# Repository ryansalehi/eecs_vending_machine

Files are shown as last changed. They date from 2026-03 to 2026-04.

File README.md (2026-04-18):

# EECS Sticker Vending Machine
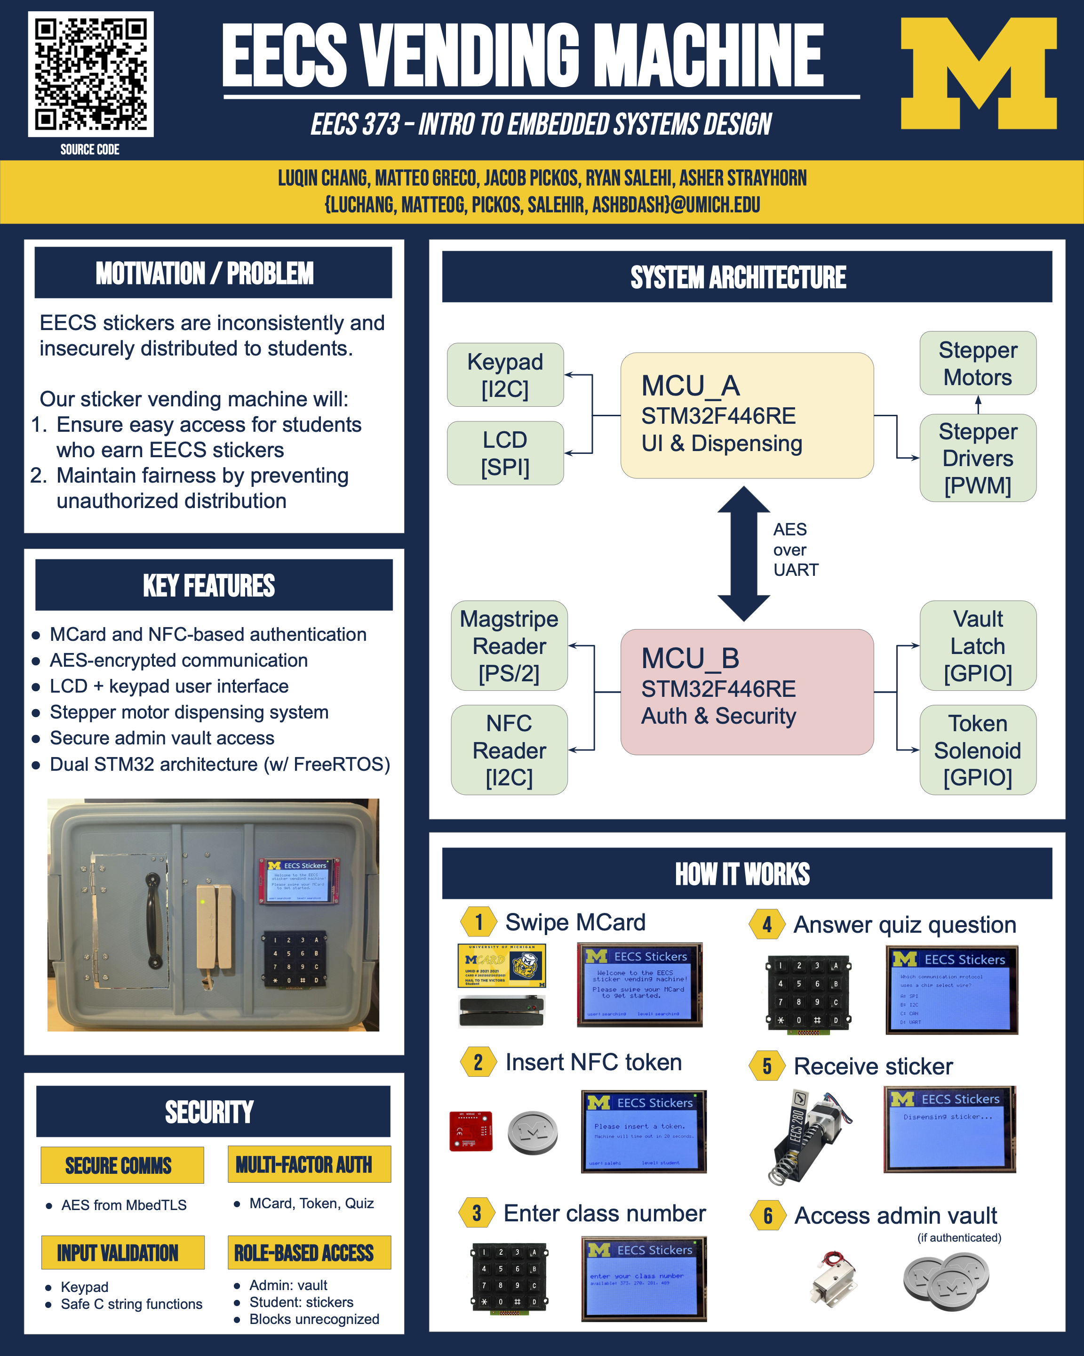
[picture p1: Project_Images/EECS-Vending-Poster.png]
Poster for Project Expo


# MCU_A Pinout
LCD:
- PA4 CS
- PB0 RESET
- PB1 DC
- PA7 MOSI
- PA6 MISO
- PB3 SCK
- 3.3V LED

Keypad:
- PB6 SCL
- PB9 SDA
- PA9 INT

UART:
- PC10 UART_TX
- PC11 UART_RX

Motors:
- PC8 Step
- PC9 Dir
- PB4 EN1
- PB5 EN2
- PB13 EN3
- PB14 EN4

# MCU_B Pinout
Token NFC:
- PB8 SCL
- PB9 SDA
- PC13 IRQ
- PA8 RESET

PS/2 Magstripe Reader:
- PC0 CLOCK
- PC1 DATA

UART:
- PC10 UART_TX
- PC11 UART_RX

DOOR LATCHES:
- PC2 ADMIN DOOR
- PC3 TOKEN DROP

# Keypad Pinout

With pin 0 as the pin closest to the * button:
- Pin 0: Row 1
- Pin 1: Row 2
- Pin 2: Col 0
- Pin 3: Row 3
- Pin 4: Col 1
- Pin 5: Col 2
- Pin 6: Col 3
- Pin 7: Row 0

When read, column value is 1-based and row value is 0-based

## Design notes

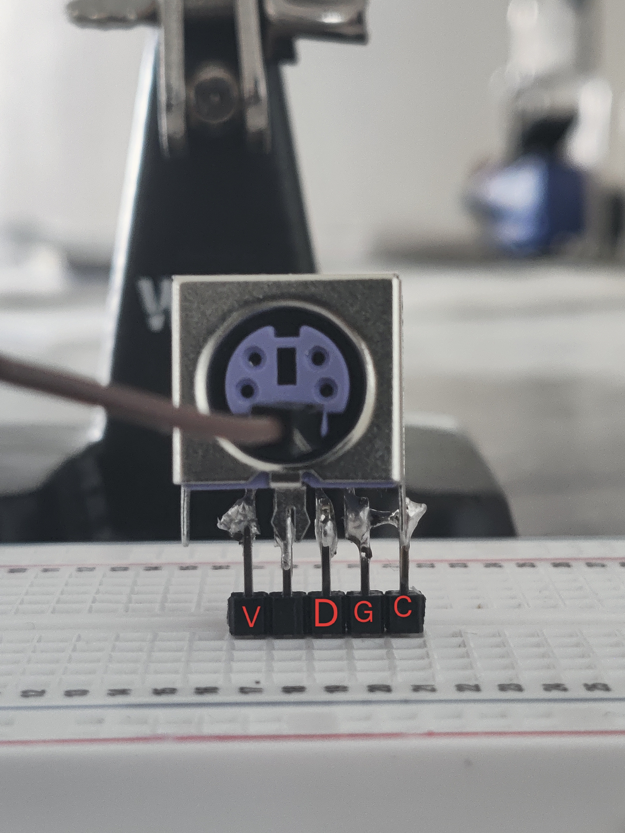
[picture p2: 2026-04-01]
Datasheets/ps2-connector-pinout.jpg

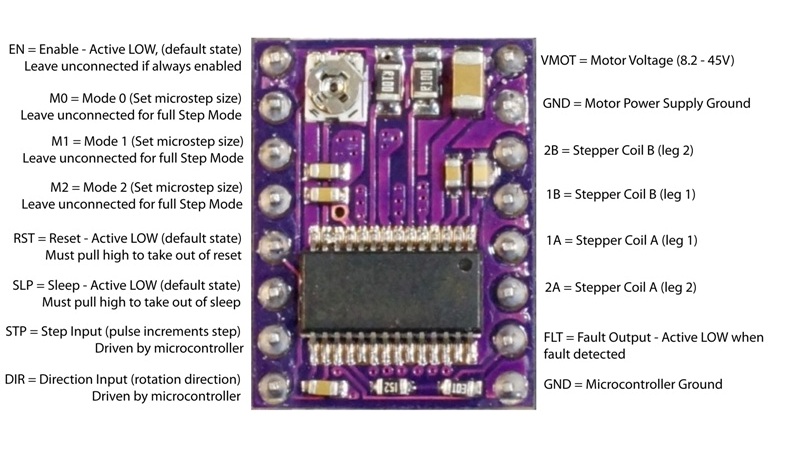
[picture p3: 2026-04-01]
Datasheets/DRV8825-Pinout-2.jpg

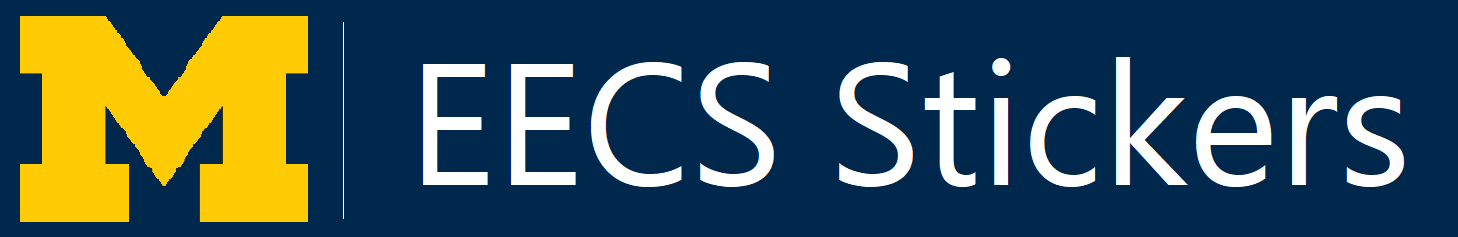
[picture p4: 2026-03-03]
Project_Images/header.png

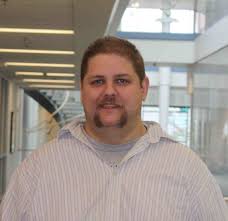
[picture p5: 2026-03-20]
Datasheets/ronald.jpg

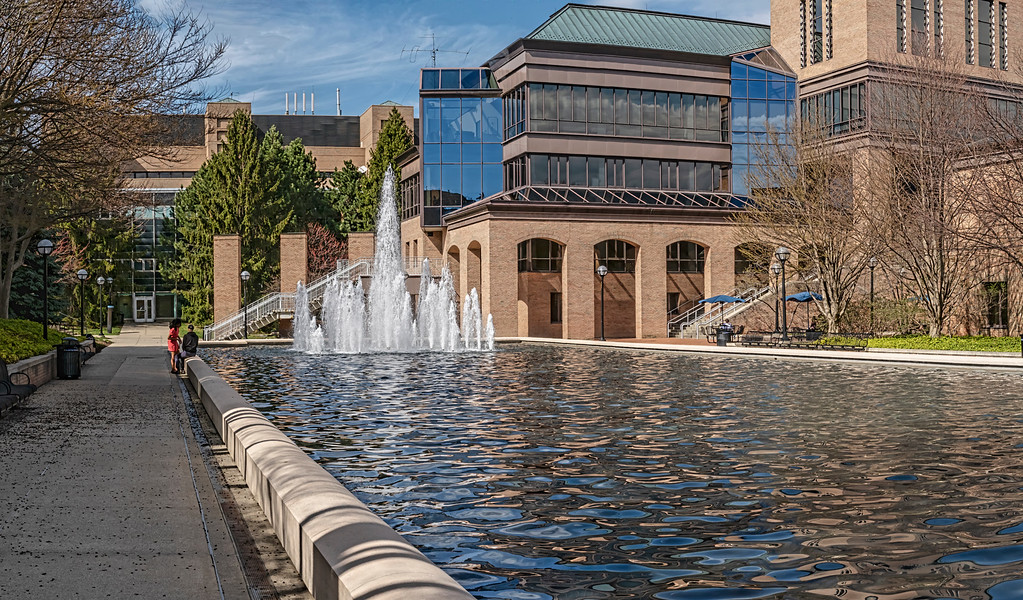
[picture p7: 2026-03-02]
Project_Images/north.png

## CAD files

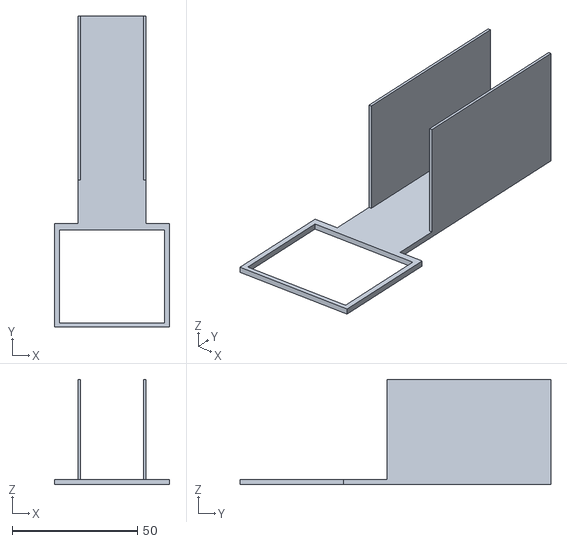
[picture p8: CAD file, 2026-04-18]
CAD/Incredible Stantia-Jofo.stl
46.0 x 124.3 x 42.0

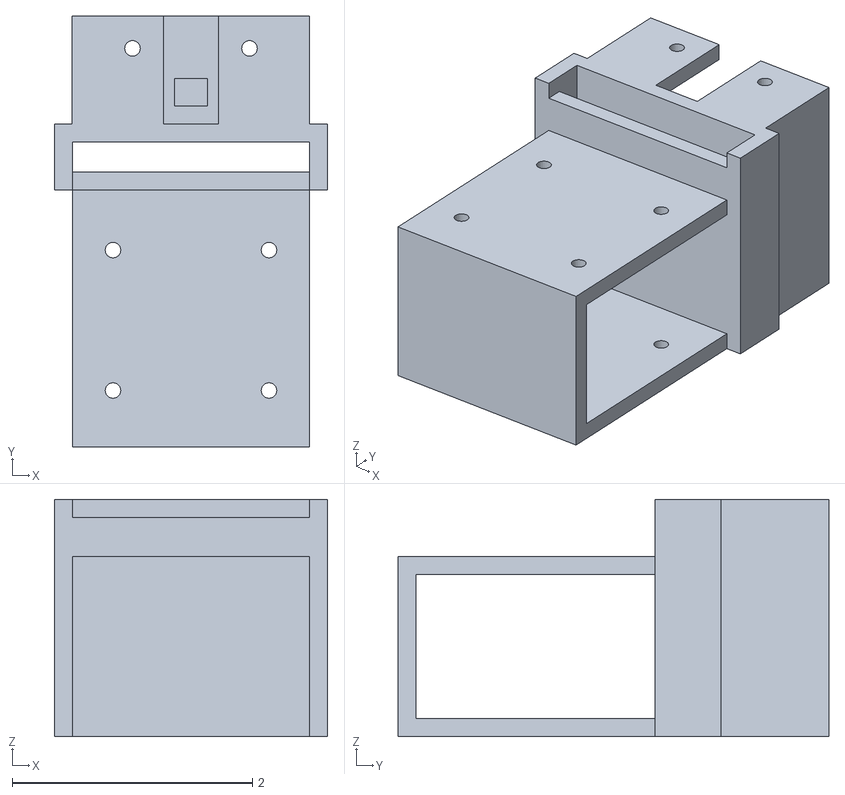
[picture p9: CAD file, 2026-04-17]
CAD/NFCHolderWithLatch.stl
2.28 x 3.59 x 1.97

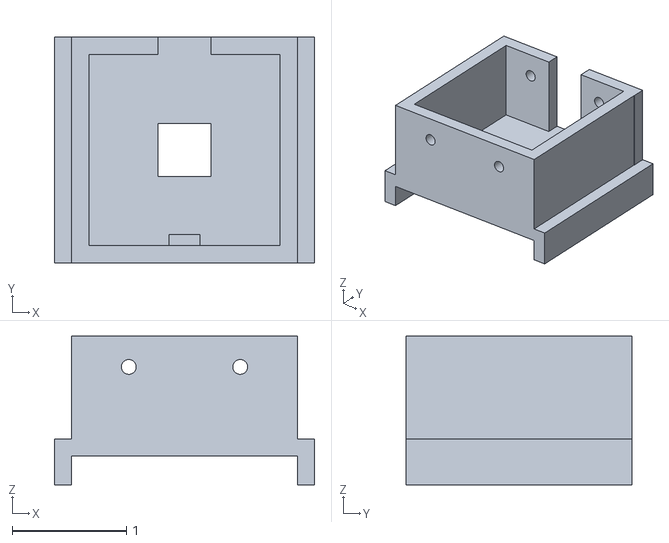
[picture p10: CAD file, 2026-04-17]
CAD/NFCHolder.stl
2.28 x 1.97 x 1.30

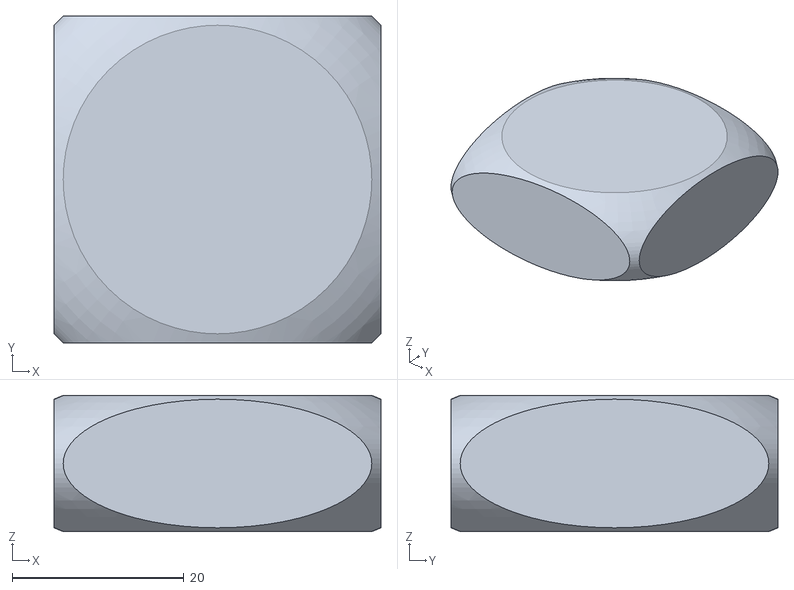
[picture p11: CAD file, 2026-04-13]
CAD/Stunning Albar-Crift.stl
38.1 x 38.1 x 15.9

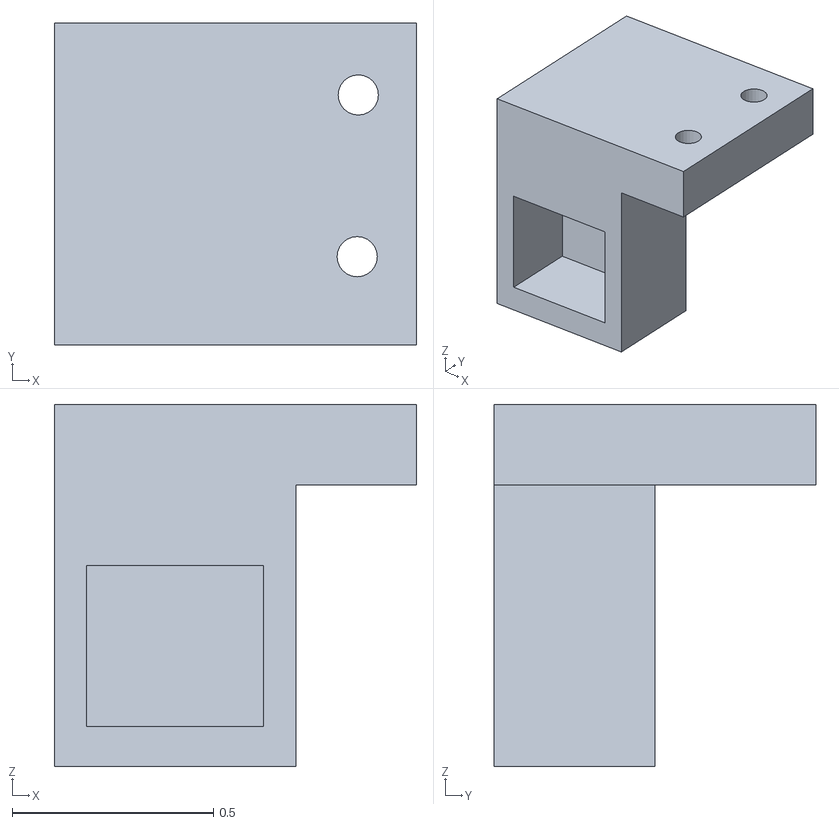
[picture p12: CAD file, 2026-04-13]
CAD/latch.stl
0.9 x 0.8 x 0.9

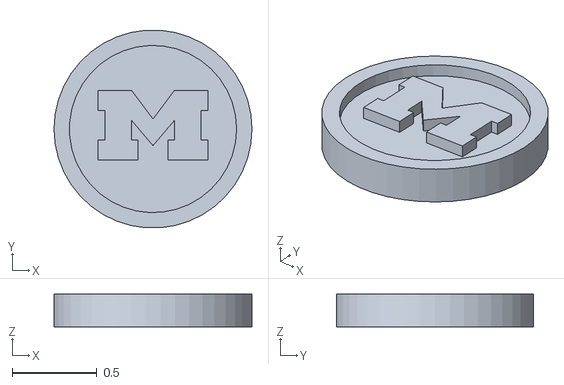
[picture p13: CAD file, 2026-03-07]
CAD/Token_v1_2.stl
1.17 x 1.17 x 0.195

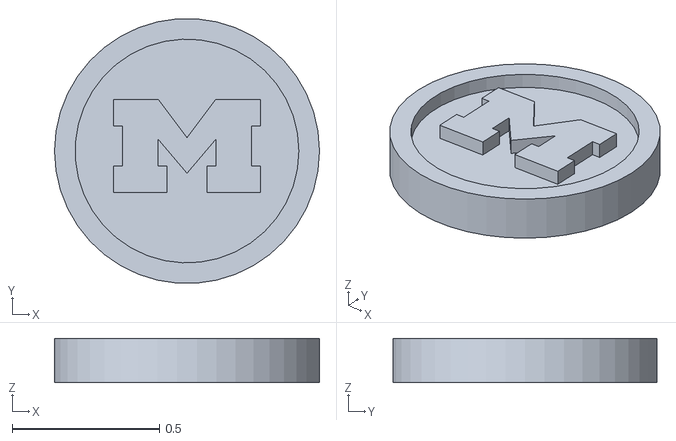
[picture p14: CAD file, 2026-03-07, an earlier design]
CAD/Token_v1_1.stl
0.9 x 0.897 x 0.15

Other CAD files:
CAD/Token.dwg
CAD/NFCHolder.dwg
CAD/NFCHolderWithLatch.dwg
CAD/latch.dwg

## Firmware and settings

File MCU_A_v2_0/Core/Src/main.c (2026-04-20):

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
/* Includes ------------------------------------------------------------------*/
#include "main.h"
#include "cmsis_os.h"
#include "mbedtls.h"

/* USER CODE BEGIN Includes */
#include "lcd.h"
#include "keypad.h"
#include "motors.h"
#include "sender.h"
#include "receiver.h"
#include "statemachine.h"

/* USER CODE END Includes */

I2C_HandleTypeDef hi2c1;

SPI_HandleTypeDef hspi1;

TIM_HandleTypeDef htim3;

UART_HandleTypeDef huart3;

/* Definitions for LCDTask */
osThreadId_t LCDTaskHandle;
const osThreadAttr_t LCDTask_attributes = {
  .name = "LCDTask",
  .stack_size = 128 * 4,
  .priority = (osPriority_t) osPriorityNormal,
};
/* Definitions for KEYPADTask */
osThreadId_t KEYPADTaskHandle;
const osThreadAttr_t KEYPADTask_attributes = {
  .name = "KEYPADTask",
  .stack_size = 128 * 4,
  .priority = (osPriority_t) osPriorityLow,
};
/* Definitions for UARTTask */
osThreadId_t UARTTaskHandle;
const osThreadAttr_t UARTTask_attributes = {
  .name = "UARTTask",
  .stack_size = 128 * 4,
  .priority = (osPriority_t) osPriorityLow,
};
/* Definitions for HEARTBEATTask */
osThreadId_t HEARTBEATTaskHandle;
const osThreadAttr_t HEARTBEATTask_attributes = {
  .name = "HEARTBEATTask",
  .stack_size = 128 * 4,
  .priority = (osPriority_t) osPriorityLow,
};
/* Definitions for SMTask */
osThreadId_t SMTaskHandle;
const osThreadAttr_t SMTask_attributes = {
  .name = "SMTask",
  .stack_size = 256 * 4,
  .priority = (osPriority_t) osPriorityLow,
};
void SystemClock_Config(void);
static void MX_GPIO_Init(void);
static void MX_I2C1_Init(void);
static void MX_SPI1_Init(void);
static void MX_USART3_UART_Init(void);
static void MX_TIM3_Init(void);
void StartLCDTask(void *argument);
void StartKEYPADTask(void *argument);
void StartUARTTask(void *argument);
void StartHEARTBEATTask(void *argument);
void StartSMTask(void *argument);

/**
  * @brief  The application entry point.
  * @retval int
  */
int main(void)
{

  /* MCU Configuration--------------------------------------------------------*/

  /* Reset of all peripherals, Initializes the Flash interface and the Systick. */
  HAL_Init();

  /* Configure the system clock */
  SystemClock_Config();

  /* Initialize all configured peripherals */
  MX_GPIO_Init();
  MX_I2C1_Init();
  MX_SPI1_Init();
  MX_USART3_UART_Init();
  MX_TIM3_Init();
  /* Call PreOsInit function */
  MX_MBEDTLS_Init();
  /* USER CODE BEGIN 2 */
  Receiver_StartHardwareListening();

  /* USER CODE END 2 */

  /* Init scheduler */
  osKernelInitialize();

  /* USER CODE BEGIN RTOS_MUTEX */
  LCD_Init();
  KEYPAD_Init();
  UART_Init();
  /* USER CODE END RTOS_MUTEX */

  /* USER CODE BEGIN RTOS_SEMAPHORES */
  /* add semaphores, ... */
  /* USER CODE END RTOS_SEMAPHORES */

  /* USER CODE BEGIN RTOS_TIMERS */
  /* start timers, add new ones, ... */
  /* USER CODE END RTOS_TIMERS */

  /* USER CODE BEGIN RTOS_QUEUES */
  /* add queues, ... */
  /* USER CODE END RTOS_QUEUES */

  /* Create the thread(s) */
  /* creation of LCDTask */
  LCDTaskHandle = osThreadNew(StartLCDTask, NULL, &LCDTask_attributes);

  /* creation of KEYPADTask */
  KEYPADTaskHandle = osThreadNew(StartKEYPADTask, NULL, &KEYPADTask_attributes);

  /* creation of UARTTask */
  UARTTaskHandle = osThreadNew(StartUARTTask, NULL, &UARTTask_attributes);

  /* creation of HEARTBEATTask */
  HEARTBEATTaskHandle = osThreadNew(StartHEARTBEATTask, NULL, &HEARTBEATTask_attributes);

  /* creation of SMTask */
  SMTaskHandle = osThreadNew(StartSMTask, NULL, &SMTask_attributes);

  /* USER CODE BEGIN RTOS_THREADS */
  /* add threads, ... */
  /* USER CODE END RTOS_THREADS */

  /* USER CODE BEGIN RTOS_EVENTS */
  /* add events, ... */
  /* USER CODE END RTOS_EVENTS */

  /* Start scheduler */
  osKernelStart();

  /* We should never get here as control is now taken by the scheduler */

  /* Infinite loop */
  /* USER CODE BEGIN WHILE */
  while (1)
  {
    /* USER CODE END WHILE */
    /* USER CODE BEGIN 3 */
    osDelay(5000);

  }
  /* USER CODE END 3 */
}

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
/* USER CODE BEGIN 4 */
void HAL_GPIO_EXTI_Callback(uint16_t GPIO_Pin)
{
  KEYPAD_IrqFromIsr();
}
/* USER CODE END 4 */

/* USER CODE BEGIN Header_StartLCDTask */
/**
  * @brief  Function implementing the LCDTask thread.
  * @param  argument: Not used
  * @retval None
  */
/* USER CODE END Header_StartLCDTask */
void StartLCDTask(void *argument)
{
  /* USER CODE BEGIN 5 */
  /* Infinite loop */
  for(;;)
  {
    LCD_Render();
    osDelay(1);
  }
  /* USER CODE END 5 */
}

/* USER CODE BEGIN Header_StartKEYPADTask */
/**
* @brief Function implementing the KEYPADTask thread.
* @param argument: Not used
* @retval None
*/
/* USER CODE END Header_StartKEYPADTask */
void StartKEYPADTask(void *argument)
{
  /* USER CODE BEGIN StartKEYPADTask */
  /* Infinite loop */
  for(;;)
  {
    KEYPAD_ReadAnyPresses();
    osDelay(1);
  }
  /* USER CODE END StartKEYPADTask */
}

/* USER CODE BEGIN Header_StartUARTTask */
/**
* @brief Function implementing the UARTTask thread.
* @param argument: Not used
* @retval None
*/
/* USER CODE END Header_StartUARTTask */
void StartUARTTask(void *argument)
{
  /* USER CODE BEGIN StartUARTTask */
  for(;;)
  {
    Receiver_Process();
  }
  /* USER CODE END StartUARTTask */
}

/* USER CODE BEGIN Header_StartHEARTBEATTask */
/**
* @brief Function implementing the HEARTBEATTask thread.
* @param argument: Not used
* @retval None
*/
/* USER CODE END Header_StartHEARTBEATTask */
void StartHEARTBEATTask(void *argument)
{
  /* USER CODE BEGIN StartHEARTBEATTask */
  uint8_t val = 0;
  
  for(;;)
  {
    val++;
	  HAL_GPIO_TogglePin(GPIOA, GPIO_PIN_5); // Toggle Blue LED
    LCD_BeginFrame();
    if(val % 2 == 0)
    {
      LCD_FillRect(470, 0, 10, 10, 0, 39, 76);
    }
    else
    {
      LCD_FillRect(470, 0, 10, 10, 0, 255, 0);
    }
    LCD_EndFrame();
	  osDelay(1000);                          // DO NOT use HAL_Delay() here
  }
  /* USER CODE END StartHEARTBEATTask */
}

/* USER CODE BEGIN Header_StartSMTask */
/**
* @brief Function implementing the SMTask thread.
* @param argument: Not used
* @retval None
*/
/* USER CODE END Header_StartSMTask */
void StartSMTask(void *argument)
{
  /* USER CODE BEGIN StartSMTask */
  /* Infinite loop */
  for(;;)
  {
    SM_Run();
  }
  /* USER CODE END StartSMTask */
}

/**
  * @brief  Period elapsed callback in non blocking mode
  * @note   This function is called  when TIM6 interrupt took place, inside
  * HAL_TIM_IRQHandler(). It makes a direct call to HAL_IncTick() to increment
  * a global variable "uwTick" used as application time base.
  * @param  htim : TIM handle
  * @retval None
  */
void HAL_TIM_PeriodElapsedCallback(TIM_HandleTypeDef *htim)
{
  if (htim->Instance == TIM6)
  {
    HAL_IncTick();
  }
}

/**
  * @brief  This function is executed in case of error occurrence.
  * @retval None
  */
void Error_Handler(void)
{
  /* USER CODE BEGIN Error_Handler_Debug */
  /* User can add his own implementation to report the HAL error return state */
  __disable_irq();
  while (1)
  {
  }
  /* USER CODE END Error_Handler_Debug */
}
#ifdef USE_FULL_ASSERT
/**
  * @brief  Reports the name of the source file and the source line number
  *         where the assert_param error has occurred.
  * @param  file: pointer to the source file name
  * @param  line: assert_param error line source number
  * @retval None
  */
void assert_failed(uint8_t *file, uint32_t line)
{
  /* USER CODE BEGIN 6 */
  /* User can add his own implementation to report the file name and line number,
     ex: printf("Wrong parameters value: file %s on line %d\r\n", file, line) */
  /* USER CODE END 6 */
}
#endif /* USE_FULL_ASSERT */

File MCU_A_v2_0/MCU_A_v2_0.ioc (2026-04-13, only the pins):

Mcu.UserName=STM32F446RETx
PA13.GPIO_Label=TMS
PA13.Signal=SYS_JTMS-SWDIO
PA14.GPIO_Label=TCK
PA14.Signal=SYS_JTCK-SWCLK
PA2.GPIO_Label=USART_TX
PA2.Signal=USART2_TX
PA3.GPIO_Label=USART_RX
PA3.Signal=USART2_RX
PA4.Signal=GPIO_Output
PA5.GPIO_Label=LD2 [Green Led]
PA5.Signal=GPIO_Output
PA6.Signal=SPI1_MISO
PA7.Signal=SPI1_MOSI
PA9.Signal=GPXTI9
PB0.Signal=GPIO_Output
PB1.Signal=GPIO_Output
PB13.GPIO_Label=enable_motor3
PB13.Signal=GPIO_Output
PB14.GPIO_Label=enable_motor4
PB14.Signal=GPIO_Output
PB3.Signal=SPI1_SCK
PB4.GPIO_Label=enable_motor1
PB4.Signal=GPIO_Output
PB5.GPIO_Label=enable_motor2
PB5.Signal=GPIO_Output
PB6.Signal=I2C1_SCL
PB9.Signal=I2C1_SDA
PC10.Signal=USART3_TX
PC11.Signal=USART3_RX
PC13.GPIO_Label=B1 [Blue PushButton]
PC13.Signal=GPXTI13
PC14-OSC32_IN.Signal=RCC_OSC32_IN
PC15-OSC32_OUT.Signal=RCC_OSC32_OUT
PC8.GPIO_Label=motor_step
PC8.Signal=S_TIM3_CH3
PC9.GPIO_Label=motor_direction
PC9.Signal=GPIO_Output
PH0-OSC_IN.Signal=RCC_OSC_IN
PH1-OSC_OUT.Signal=RCC_OSC_OUT

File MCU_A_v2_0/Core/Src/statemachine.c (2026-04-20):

/**
 * @date April 10, 2026
 */

#include "statemachine.h"
#include <stdbool.h>

#include "lcd.h"
#include "sender.h"
#include "motors.h"
#include "keypad.h"
#include "question.h"
#include "happy_out.h"

typedef struct
{
    /**
     * MCard Reading
     */
    volatile bool name_set;
    char mcard_name[16];

    volatile bool level_set;
    int mcard_level;

    /**
     * Token Reading
     */
    volatile bool token_set;
    volatile bool invalid_token;

    /**
     * Class/keypad Reading
     */
    int class;
    char class_string[4];

    /*
    Current question waiting for the answer
    */
    const Question *q;
} State_ctx_t;

typedef void (*statePtr)(State_ctx_t*);

extern TIM_HandleTypeDef htim3;

static statePtr next_state;
static State_ctx_t context;

void SM_Idle(State_ctx_t* ctx);
void SM_NFCWait(State_ctx_t* ctx);
void SM_InvalidToken(State_ctx_t* ctx);
void SM_UnlockVault(State_ctx_t* ctx);
void SM_Denied(State_ctx_t* ctx);
void SM_ClassSelection(State_ctx_t* ctx);
void SM_Question(State_ctx_t* ctx);
void SM_WrongAnswer(State_ctx_t* ctx);
void SM_InvalidInput(State_ctx_t* ctx);
void SM_Dispense(State_ctx_t* ctx);

void SM_Run()
{
    memset(&context, 0, sizeof(context));
    next_state = SM_Idle;
    while(true)
    {
        if(next_state)
        {
            next_state(&context);
        }
        else
        {
            // we're cooked, shouldn't get here
            next_state = SM_Idle;
        }
    }
}

void SM_SetNewName(char*name)
{
    strcpy(context.mcard_name, name);
    context.name_set = true;
}

void SM_SetLevel(int level)
{
    context.mcard_level = level;
    context.level_set = true;
}

void SM_SetToken()
{
    context.token_set = true;
}

void SM_SetInvalidToken()
{
    context.invalid_token = true;
}

void SM_Idle(State_ctx_t* ctx)
{
    // start a new cycle 
    memset(&context, 0, sizeof(context));
    next_state = SM_Idle;

    // print to LCD "Hello, please swipe MCard"
    LCD_BeginFrame();
    LCD_FillRect(0, 71, 480, 249, 228, 228, 228); // fill working area with white
    LCD_DrawText(60, 100, "Welcome to the EECS", 45, 3);
    LCD_DrawText(38, 128, "sticker vending machine!", 45, 3);
    LCD_DrawText(38, 175, "Please swipe your MCard", 45, 3);
    LCD_DrawText(80, 203, "to get started.", 45, 3);
    LCD_DrawText(15, 290, "user: ", 155, 2);
    LCD_DrawText(80, 290, "searching", 155, 2);
    LCD_DrawText(240, 290, "level: ", 155, 2);
    LCD_DrawText(320, 290, "searching", 155, 2);
    LCD_EndFrame();

    // Get MCard Name
    while(true)
    {
        if(ctx->name_set) {
        	if (ctx->level_set)
        {
            break;
        }
        }
    }

//    uint32_t start_wait = HAL_GetTick();
//    while(true)
//    {
//        if((HAL_GetTick() - start_wait) > 5000) // wait 5s max for the level to come in after the name
//        {
//            // didn't get response
//            next_state = SM_Denied;
//            return;
//        }
//    }

    LCD_BeginFrame();
    LCD_FillRect(0, 71, 480, 249, 228, 228, 228); // fill working area with white
    LCD_DrawText(15, 290, "user: ", 155, 2);
    LCD_DrawText(80, 290, ctx->mcard_name, 155, 2);
    LCD_DrawText(240, 290, "level: ", 155, 2);
    switch(ctx->mcard_level)
    {
        case 1:
            // student
            LCD_DrawText(320, 290, "student", 155, 2);
            next_state = SM_NFCWait;
            break;
        case 2:
            // admin
            LCD_DrawText(320, 290, "admin", 155, 2);
            next_state = SM_UnlockVault;
            break;
        case 3:
            // fall through intentional
        default:
            // unauthorized / denied
            LCD_DrawText(320, 290, "unrecognized", 155, 2);
            next_state = SM_Denied;
            break;
    }
    LCD_EndFrame();
}

void SM_NFCWait(State_ctx_t* ctx)
{
    LCD_BeginFrame();
    LCD_FillRect(0, 71, 480, 219, 228, 228, 228); // fill working area with white
    LCD_DrawText(38, 128, "Please insert a token.", 45, 3);
    LCD_DrawText(38, 175, "Machine will time out in 20 seconds.", 45, 2);
    LCD_EndFrame();

    ctx->token_set = false;
    ctx->invalid_token = false;

    // Get token reading
    uint32_t start_wait = HAL_GetTick();
    while(true)
    {
        if((HAL_GetTick() - start_wait) > 20000) // wait 20s max
        {
            // didn't get response
            next_state = SM_Denied;
            return;
        }
        if(ctx->token_set)
        {
            break;
        }
        if(ctx->invalid_token)
        {
            next_state = SM_InvalidToken;
            return;
        }
        osDelay(5);
    }

    LCD_BeginFrame();
    LCD_FillRect(0, 71, 480, 249, 228, 228, 228); // fill working area with white
    LCD_DrawText(38, 128, "Valid token received!", 45, 3);
    LCD_EndFrame();
    osDelay(1500);
    next_state = SM_ClassSelection;
}

void SM_InvalidToken(State_ctx_t* ctx)
{
    LCD_BeginFrame();
    LCD_FillRect(0, 71, 480, 249, 228, 228, 228); // fill working area with white
    LCD_DrawText(38, 128, "Invalid token :(", 45, 3);
    LCD_EndFrame();
    osDelay(2000);
    next_state = SM_Idle;
}

void SM_UnlockVault(State_ctx_t* ctx)
{
    LCD_BeginFrame();
    LCD_FillRect(0, 71, 480, 219, 228, 228, 228); // fill working area with white
    LCD_DrawText(38, 128, "Vault unlocked.", 45, 3);
    LCD_DrawText(38, 156, "Combustion Imminent.", 45, 3);
    LCD_EndFrame();

    osDelay(5000);
    next_state = SM_Idle;
}

void SM_Denied(State_ctx_t* ctx)
{
    LCD_BeginFrame();
    LCD_FillRect(0, 71, 480, 249, 228, 228, 228); // fill working area with white
    LCD_DrawText(38, 128, "Access Denied.", 45, 3);
    LCD_EndFrame();
    osDelay(3000);

    next_state = SM_Idle;
}

void SM_ClassSelection(State_ctx_t* ctx)
{
    Class_t class_selection;    
    if(KEYPAD_PromptClassNumber(&class_selection)) 
    {
        switch(class_selection.number_int)
        {
            case 373: 
                // fall through intentional
            case 281:
                // fall through intentional
            case 270:
                // fall through intentional
            case 489: 
                ctx->class = class_selection.number_int;
                memcpy(ctx->class_string, class_selection.number_string, 4);
                next_state = SM_Question;
                break;
            case 1: // 1 means exit
                next_state = SM_Idle;
                break;
            default: 
                next_state = SM_InvalidInput;
                break;
        }
    }
    else
    {
        next_state = SM_InvalidInput;
    }
}
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

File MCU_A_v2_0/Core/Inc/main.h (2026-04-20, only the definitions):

#define B1_Pin GPIO_PIN_13
#define B1_GPIO_Port GPIOC
#define B1_EXTI_IRQn EXTI15_10_IRQn
#define USART_TX_Pin GPIO_PIN_2
#define USART_TX_GPIO_Port GPIOA
#define USART_RX_Pin GPIO_PIN_3
#define USART_RX_GPIO_Port GPIOA
#define LD2_Pin GPIO_PIN_5
#define LD2_GPIO_Port GPIOA
#define enable_motor3_Pin GPIO_PIN_13
#define enable_motor3_GPIO_Port GPIOB
#define enable_motor4_Pin GPIO_PIN_14
#define enable_motor4_GPIO_Port GPIOB
#define motor_step_Pin GPIO_PIN_8
#define motor_step_GPIO_Port GPIOC
#define motor_direction_Pin GPIO_PIN_9
#define motor_direction_GPIO_Port GPIOC
#define TMS_Pin GPIO_PIN_13
#define TMS_GPIO_Port GPIOA
#define TCK_Pin GPIO_PIN_14
#define TCK_GPIO_Port GPIOA
#define enable_motor1_Pin GPIO_PIN_4
#define enable_motor1_GPIO_Port GPIOB
#define enable_motor2_Pin GPIO_PIN_5
#define enable_motor2_GPIO_Port GPIOB

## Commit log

2026-03-02 LCD: Print a real, color image
2026-03-02 LCD: Speed up screen print by a huge amount (15x)
2026-03-03 LCD: Create general thread-safe API
2026-03-03 LCD: Add text print to screen
2026-03-06 REPO: Organize loose files into a better structure
    [main.c]
2026-03-07 CAD: Create first model of token
    [Token.dwg, Token_v1_1.stl]
2026-03-07 CAD: Increase scale by 1.35x
    [Token.dwg, Token_v1_2.stl]
2026-03-19 PS/2: Implement most of a read only PS/2 protocol
    PC0 is connected to the PS/2 device's clock. It is set to be
    a falling edge external interrupt. Each falling edge,
    the interrupt will sample from the PS/2 device's data line,
    which is assigned to PC1 as a GPIO-input.
    Needs to be tested.
2026-03-20 Add UART pin assignments and update pinout details
2026-03-20 Modify keypad section and include I2C details
    Updated keypad connections and added I2C pins.
2026-03-25 Change UART pin assignments for TX and RX
    Updated UART pin assignments in the README. The old pins were used by the manufacturer as debug pins already.
2026-03-25 Update UART pin assignments in README
    working uart pin assignment
2026-04-01 Pinout diagram for stepper motor driver
2026-04-01 PS/2 connector pinout diagram
2026-04-02 Add motor pin assignments to README
2026-04-07 add datasheet, fix address shift off by one
    [keypad.c]
2026-04-07 KEYPAD: Fix init and interrupt, keypad is now working
    [main.c]
2026-04-07 KEYPAD: Only log button press (not release)
2026-04-07 V2: Port in jacobs motor work
2026-04-07 UART: Port into V2
2026-04-07 UART: Working demo, blinks led when A pressed
2026-04-08 UART: Add todo for integration
2026-04-08 V2: Bring over jacobs ps2 changes (need to check pin cfg)
2026-04-08 V2: Setup motor integration
2026-04-08 Motors: Change motor_enable pins to active high, change PSC
2026-04-09 PS/2: Read from data pin inside ISR
2026-04-13 INTEGRATION: Fix pins and get latch working
    [MCU_B_v2_0.ioc, main.c, ps2.c]
2026-04-13 INTEGRATION: Add CAD files for pads and latch lock
    [Stunning Albar-Crift.stl, latch.dwg, latch.stl]
2026-04-14 Adjust MCU_B, trying to fix NFC
    [main.c]
2026-04-17 Change terminator for UART
2026-04-17 INTEGRATION2: Fix exit class number edge case
    [keypad.c]
2026-04-17 INTEGRATION2: Add wrong answer state
    [statemachine.c]
2026-04-17 INTEGRATION2: Design token chamber
    [NFCHolder.dwg, NFCHolder.stl, NFCHolderWithLatch.dwg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]
2026-04-18 INTEGRATION3: Fix PS2 EMI issue
    [main.c, ps2.c]
2026-04-18 INTEGRATION3: Fix NFC EMI issue
    [main.c, nfc2.c, statemachine.c]
2026-04-18 INTEGRATION3: Print selection help
2026-04-18 INTEGRATION3: Upload CAD for motor housing and add research poster
    [Incredible Stantia-Jofo.stl]

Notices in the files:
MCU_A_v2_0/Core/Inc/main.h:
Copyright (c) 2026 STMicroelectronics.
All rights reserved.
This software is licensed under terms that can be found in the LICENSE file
